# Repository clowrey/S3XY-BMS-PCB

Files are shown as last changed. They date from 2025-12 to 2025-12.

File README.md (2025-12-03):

# isoSPI-M3Y-BMS-PCB

**Hardware Design for Tesla Model 3/Y Battery Management System**





This repository contains the **KiCad PCB design files** for a replacement Battery Management System (BMS) designed for Tesla Model 3 and Model Y battery packs. This hardware interfaces with high-voltage (400V) battery modules using the isoSPI protocol and provides comprehensive monitoring, control, and safety features.

🔗 **Companion Firmware Repository:** [isoSPI-M3Y-BMS](https://github.com/clowrey/isoSPI-M3Y-BMS)

---

## ⚡ Overview

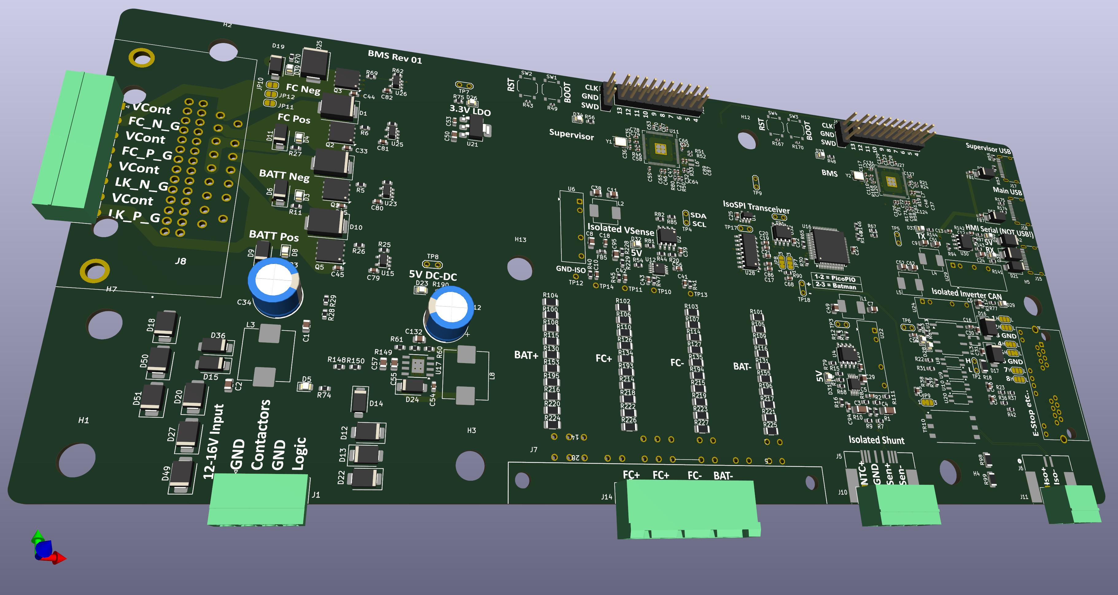
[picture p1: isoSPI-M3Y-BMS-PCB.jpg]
PCB Design


This PCB design implements a complete BMS controller capable of:

- **Direct BMB Communication**: isoSPI master interface for Battery Management Boards
- **High Precision Monitoring**: Current, voltage, temperature, and power measurement
- **CAN Bus Integration**: 500kbps communication with vehicle systems and inverters
- **Contactor Control**: Safe sequenced activation of high-voltage contactors
- **Cell Balancing**: Individual cell balancing control through BMB modules
- **Safety Features**: Overcurrent, overvoltage, undervoltage, and thermal protection

### 🔋 Tesla Model 3/Y Battery Pack Architecture

Tesla Model 3 and Model Y battery packs utilize a modular architecture:

- **Cell Configuration:** 4416 cells (96s46p) in 4 modules
- **Module Configuration:** 24 cells in series per module (96 total series groups)
- **Nominal Voltage:** ~350V (fully charged: ~400V, discharged: ~280V)
- **Capacity:** Varies by pack (50-82 kWh depending on model/year)
- **Battery Management Boards (BMBs):** Each module contains BMBs that monitor cell groups
- **Communication:** Original packs use proprietary Tesla BMS; this project replaces it

**Why Replace the BMS?**
- Reuse Tesla packs in DIY electric vehicle conversions
- Second-life energy storage systems
- Research and educational purposes
- Open-source alternative to proprietary systems

### 🔌 Key Hardware Features

| Feature | Implementation |
|---|---|
| **Microcontroller** | Raspberry Pi RP2354B (dual Cortex-M33, 150MHz) |
| **Current Sensing** | Texas Instruments INA228 (20-bit ADC) |
| **Pack Voltage** | 4-channel ADC with precision voltage dividers |
| **CAN Interface** | Hardware CAN transceiver (500kbps) |
| **isoSPI** | Differential Manchester encoding, galvanic isolation |
| **Contactor Drivers** | 4-channel PWM with inrush control |
| **Operating Voltage** | 12V nominal input |
| **High Voltage Rating** | Up to 400V DC battery pack |

---

## 📁 Repository Structure

```
isoSPI-M3Y-BMS-PCB/
├── isoSPI-M3Y-BMS-PCB.kicad_pro    # KiCad project file
├── isoSPI-M3Y-BMS-PCB.kicad_sch    # Main schematic design
├── isoSPI-M3Y-BMS-PCB.kicad_pcb    # PCB layout
├── BMS_Library/                     # Custom component library
│   ├── BMS_Library.kicad_sym        # Symbol library
│   └── BMS_Library.pretty/          # Footprint library
├── RP2350_KiCad/                    # RP2350 MCU resources
│   ├── RP2350A_QFN-60*.kicad_mod    # Footprints
│   ├── RP2350A-QFN60.step           # 3D model
│   └── rp2350a-qfn60.kicad_sym      # Symbol
├── bms.3dshapes/                    # 3D models for connectors
├── reassociate_components.py        # Component re-linking utility
├── apply_mapping.py                 # Reference mapping tool
└── fabrication-toolkit-options.json # Manufacturing outputs config
```

---

## 🚀 Getting Started

### Prerequisites

- **KiCad 8.0+** - [Download here](https://www.kicad.org/download/)
- **Python 3.7+** (for utility scripts)
- Basic understanding of PCB design and high-voltage safety

### Opening the Project

1. **Clone the repository:**
   ```bash
   git clone https://github.com/clowrey/isoSPI-M3Y-BMS-PCB.git
   cd isoSPI-M3Y-BMS-PCB
   ```

2. **Open in KiCad:**
   - Launch KiCad
   - Open `isoSPI-M3Y-BMS-PCB.kicad_pro`

3. **Library Configuration:**
   - Libraries are configured in local `sym-lib-table` and `fp-lib-table`
   - Project-specific libraries (`BMS_Library`, `RP2350_KiCad`) should load automatically
   - If missing components appear, verify library paths in KiCad preferences

### Viewing the Design

- **Schematic:** Open `isoSPI-M3Y-BMS-PCB.kicad_sch` to view circuit design
- **PCB Layout:** Open `isoSPI-M3Y-BMS-PCB.kicad_pcb` to view board layout
- **3D View:** Press `Alt+3` in PCB editor to visualize the assembled board

---

## 🛠️ Design Sections

### Power Supply
- 12V input with protection and filtering
- 3.3V LDO for MCU and logic
- Isolated power for isoSPI interface

### Microcontroller (RP2354B)
- QFN-60 package with thermal pad
- Crystal oscillator for precision timing
- JTAG/SWD debug interface
- Boot mode selection

### Current Sensing (INA228)
- Shunt resistor-based measurement
- 20-bit delta-sigma ADC
- Bidirectional current monitoring
- I2C interface to MCU

### Voltage Monitoring
- 4-channel pack voltage measurement
- Precision resistor dividers (high voltage to ADC range)
- Individual cell voltages via isoSPI
- 12-bit internal ADC

### isoSPI Interface
- Differential transformer coupling
- Manchester encoding via PIO
- Galvanic isolation from high voltage
- Master and snooper mode support

### CAN Bus
- Hardware CAN transceiver
- 120Ω termination (configurable)
- PIO-based CAN 2.0B implementation
- 500kbps operation

### Contactor Control
- 4 independent high-current outputs
- PWM inrush current limiting
- Sequenced activation logic
- Flyback protection diodes

### Connectors
- High-voltage battery pack connector
- 12V power input
- CAN bus connector
- USB programming interface
- Debug headers

---

## 🔧 Utility Scripts

### `reassociate_components.py`

Re-links PCB footprints to schematic symbols after copying design sections. This is essential when:
- Copying and pasting PCB sections (breaks UUID links)
- Duplicating circuits for multi-channel designs
- Recovering from schematic/PCB desynchronization

**Usage:**
```bash
python reassociate_components.py
```

The script:
1. Parses both `.kicad_sch` and `.kicad_pcb` files
2. Matches components by reference designator and type
3. Updates PCB footprints with correct schematic UUIDs
4. Creates backup before modification

### `apply_mapping.py`

Applies specific component reference remapping (e.g., when renaming U11→U27). Updates both reference designators and UUID linkages.

**Usage:**
```bash
python apply_mapping.py
```

---

## 📦 Manufacturing

### Generating Production Files

The project includes `fabrication-toolkit-options.json` for automated manufacturing output generation.

**Recommended manufacturers:**
- JLCPCB
- PCBWay
- OSH Park
- Any PCB fab supporting 4+ layer boards

### PCB Specifications

| Parameter | Value |
|---|---|
| **Layers** | 4 (or as designed) |
| **PCB Thickness** | 1.6mm standard |
| **Copper Weight** | 2oz for power traces |
| **Min Trace/Space** | 6/6 mil (typical) |
| **Solder Mask** | Green (or preference) |
| **Silkscreen** | White |
| **Surface Finish** | ENIG or HASL |

### High-Voltage Considerations

⚠️ **CRITICAL SAFETY REQUIREMENTS:**

- **Clearances:** Maintain minimum 4mm creepage distance for 400V
- **Isolation:** isoSPI and current sensing must maintain galvanic isolation
- **Testing:** All HV sections require hi-pot testing before energization
- **Conformal Coating:** Recommended for high-voltage traces
- **Certifications:** May require UL/CE certification for commercial use

---

## 🔌 Assembly Notes

### Component Sourcing

- Most components available from Digi-Key, Mouser, or LCSC
- RP2354B: Available from Raspberry Pi approved distributors
- INA228: Texas Instruments or authorized distributors
- Connectors: Match to Tesla pack interface specifications

### Assembly Sequence

1. **SMD Components:** Reflow solder all surface mount parts
2. **Through-hole:** Hand solder connectors and large components
3. **Inspection:** Verify all solder joints and orientation
4. **Testing:** Low-voltage functional testing before HV connection
5. **Programming:** Flash firmware via USB or SWD
6. **Calibration:** ADC and current sensing calibration routines

---

## 🔗 Firmware Integration

This PCB is designed to work with the companion firmware:

📦 **[isoSPI-M3Y-BMS Firmware](https://github.com/clowrey/isoSPI-M3Y-BMS)**

### ✅ Implemented Features (v2.0.0)

**Hardware Drivers:**
- RP2354B microcontroller with dual Cortex-M33 cores
- INA228 current/voltage/power sensor driver
- Internal ADC for pack voltage monitoring (4 channels)
- Contactor control (4 channels, sequenced activation)
- Serial command processing (30+ commands)
- CAN bus interface (can2040, 500kbps broadcast)
- isoSPI PIO master implementation
- isoSPI passive bus snooper
- Unified BMB test interface
- Runtime interface switching (Batman/isoSPI)

**System Features:**
- Parameter system with 108+ BMS parameters
- Coulomb counting for SOC tracking
- Automatic 10Hz pack status CAN broadcasting
- Statistics tracking for TX/RX/errors
- Configurable message IDs and data formatting

### 🚧 In Progress (Phase 3)

- BATMan/isoSPI interface switching
- Runtime interface control (automatic disable/enable)
- Full BMS state machine
- Cell voltage reading via isoSPI
- Cell balancing control
- Temperature monitoring

### 📋 Pending (Phases 4-6)

- Hardware testing and validation
- Calibration routines for ADC
- Flash storage for calibration data
- Error handling and recovery
- Extended testing (24+ hours)
- Performance optimization
- Documentation completion

### Getting Started with Firmware

1. Clone the firmware repository
2. Install Pico SDK and build tools (CMake-based)
3. Build the project:
   ```bash
   cd isoSPI-M3Y-BMS
   mkdir build && cd build
   cmake ..
   make
   ```
4. Flash to RP2354B via USB or SWD
5. Connect via serial interface (115200 baud)
6. Configure using serial commands
7. Optional: Integrate with ESPHome for monitoring and display

### Optional: ESPHome Display Integration

The firmware supports integration with ESPHome for advanced monitoring via touchscreen displays:

**ESPHome Features:**
- **Three-Page Display Interface:**
  - Main overview with key parameters
  - Detailed battery information
  - Cell voltage graph (all 108 cells visualized)
- **Real-time Monitoring:** Live parameter updates every 5-10 seconds
- **Touch Controls:** Balance on/off, page navigation
- **Home Assistant Integration:** All BMS parameters as HA entities
- **Professional UI:** LVGL-based interface optimized for 480x320 displays

**Supported Hardware:**
- JC4832W535 480x320 QSPI touchscreen
- ESP32-S3 based display modules
- WiFi connectivity for OTA updates

See the [ESPHome interface documentation](https://github.com/clowrey/isoSPI-M3Y-BMS/tree/main/esphome-interface) in the firmware repository for setup instructions.

---

## ⚠️ Hardware Safety

### ⚡ HIGH VOLTAGE WARNING ⚡

**This system interfaces with 400V battery packs that can deliver LETHAL current.**

- **Only qualified personnel should work on high-voltage systems**
- **Proper isolation and safety measures required**
- **Use appropriate personal protection equipment (PPE)**
- **Follow all electrical safety protocols**
- **Discharge pack completely before service**
- **EV battery systems can deliver lethal current**
- **Follow all lockout/tagout procedures**

### ⚠️ DEVELOPMENT STATUS

- **This is a development version (v2.0.0)**
- **isoSPI implementation is experimental**
- **BATMan protocol partially implemented**
- **Extensive testing required before production use**
- **USE AT YOUR OWN RISK**
- No warranty expressed or implied
- Not certified for commercial EV use
- User assumes all responsibility for safety

### Recommended Safety Equipment

- Insulated high-voltage gloves (Class 00 minimum)
- Safety glasses with side shields
- Insulated tools rated for 1000V
- Multimeter rated for CAT III 600V or higher
- Isolation transformer for bench testing
- Emergency shutdown procedures
- First aid and emergency response plan

---

## 📚 Documentation

### Related Resources

- **Firmware Repository:** [isoSPI-M3Y-BMS](https://github.com/clowrey/isoSPI-M3Y-BMS)
- **RP2354B Datasheet:** [Raspberry Pi Documentation](https://datasheets.raspberrypi.com/rp2350/rp2350-datasheet.pdf)
- **INA228 Datasheet:** [Texas Instruments](https://www.ti.com/product/INA228)
- **Pico SDK:** [Raspberry Pi Pico SDK](https://github.com/raspberrypi/pico-sdk)
- **can2040 Library:** [Kevin O'Connor's can2040](https://github.com/KevinOConnor/can2040)
- **Original BATMan BMS:** Damien Maguire & Tom de Bree

### Additional Documentation

- Schematic PDF exports (generate from KiCad)
- Bill of Materials (generate from KiCad BOM tool)
- Assembly drawings (generate from KiCad fabrication outputs)
- Test procedures (in firmware repository)
- CAN message format documentation (in firmware repo)
- Calibration procedures (in firmware repo)

---

## 🤝 Contributing

Contributions are welcome! Please:

1. Fork the repository
2. Create a feature branch (`git checkout -b feature/improvement`)
3. Make your changes with clear commit messages
4. Test thoroughly (especially high-voltage sections)
5. Submit a pull request with detailed description

**Areas for contribution:**
- Schematic improvements
- PCB layout optimization
- Additional protection circuits
- Manufacturing DFM improvements
- Documentation enhancements
- Test jig designs

---

## 📝 License

This project is licensed under the **GNU General Public License v3.0** - see the [LICENSE](LICENSE) file for details.

This program is free software: you can redistribute it and/or modify it under the terms of the GNU General Public License as published by the Free Software Foundation, either version 3 of the License, or (at your option) any later version.

This program is distributed in the hope that it will be useful, but WITHOUT ANY WARRANTY; without even the implied warranty of MERCHANTABILITY or FITNESS FOR A PARTICULAR PURPOSE. See the GNU General Public License for more details.

**In summary:**
- ✅ Free to use, modify, and distribute
- ✅ Must disclose source code
- ✅ Must use same GPL-3.0 license
- ✅ State changes made to original
- ❌ No warranty provided

---

## 🙏 Acknowledgments

- **Damien Maguire & Tom de Bree** - Original BATMan BMS software
- **ESPHome Community** - Framework and component support
- **Kevin O'Connor** - can2040 library for RP2040/RP2350
- **Raspberry Pi Foundation** - Pico SDK and excellent documentation
- **Texas Instruments** - INA228 current sensing IC
- **KiCad Community** - Excellent open-source EDA tools
- **Analog Devices** - isoSPI protocol and reference designs
- **Tesla Motors** - Battery module architecture reference

---

## 📧 Support & Contact

- **Issues:** Use GitHub Issues for bug reports and feature requests
- **Discussions:** GitHub Discussions for general questions
- **Pull Requests:** Contributions welcome via GitHub PR

---

## 📋 Changelog

### Hardware Version 2.0 (December 2025) - RP2354B Platform

**Complete platform migration supporting firmware v2.0.0:**

#### **Major Hardware Changes**

* **Microcontroller:** Migrated from ESP32 to Raspberry Pi RP2354B
  - Dual Cortex-M33 cores @ 150MHz
  - QFN-60 package with thermal management
  - Native USB support for programming and debugging
  - Hardware SWD debug interface

* **Current Sensing:** Replaced AS8510 with Texas Instruments INA228
  - 20-bit delta-sigma ADC
  - High-side and low-side sensing capability
  - I2C interface with configurable address
  - Integrated power calculation

* **Pack Voltage Monitoring:** Added 4-channel internal ADC monitoring
  - Precision voltage dividers for 400V → 3.3V range
  - 12-bit resolution
  - Individual channel filtering

* **CAN Bus:** Integrated hardware CAN transceiver
  - Native CAN 2.0B support via PIO
  - 500kbps operation
  - Configurable termination (120Ω)

#### **New Features**

* **isoSPI Implementation:**
  - Differential transformer coupling with galvanic isolation
  - PIO-based Manchester encoding/decoding
  - Master mode for direct BMB communication
  - Passive snooper mode for bus monitoring
  - Runtime switching between BATMan SPI and isoSPI

* **Enhanced Contactor Control:**
  - 4-channel PWM drivers with inrush limiting
  - Sequenced activation logic in hardware
  - Flyback protection for inductive loads

* **Unified Testing Interface:**
  - Single test connector for both BATMan and isoSPI modes
  - Automatic interface detection

#### **Firmware Compatibility**

This hardware revision requires **firmware v2.0.0 or later** from the companion repository:
- [isoSPI-M3Y-BMS v2.0.0 Changelog](https://github.com/clowrey/isoSPI-M3Y-BMS#changelog)

### Hardware Version 1.x (2024-2025) - ESP32 Platform

**Original ESP32-based design:**
- ESP32-WROOM-32 microcontroller
- AS8510 current sensor
- Arduino framework
- BATMan SPI communication only
- ESPHome integration support

---

## ⚙️ Project Status

**Current Hardware Version:** v2.0 (RP2354B-based design)

**PCB Development Status:**
- ✅ Schematic design complete
- ✅ Component selection finalized
- 🔄 PCB layout in progress
- ⏳ Design rule check (DRC) pending
- ⏳ Prototype fabrication pending
- ⏳ Hardware validation pending
- ⏳ Production testing pending

**Companion Firmware Status:** 
- **Version:** v2.0.0 (November 2025)
- **Status:** Active development
- **Phase:** isoSPI implementation in progress (Phase 3)
- **See:** [Firmware Repository](https://github.com/clowrey/isoSPI-M3Y-BMS) for detailed status

---

## 🔮 Future Enhancements

- [ ] Enhanced thermal management
- [ ] Additional redundant safety circuits
- [ ] Wireless monitoring interface
- [ ] Integrated display option
- [ ] Automotive-grade component variants
- [ ] Extended temperature range support
- [ ] Multi-pack support with CAN bridging
- [ ] Production test fixture design

---

**⚡ Building the future of open-source battery management systems ⚡**

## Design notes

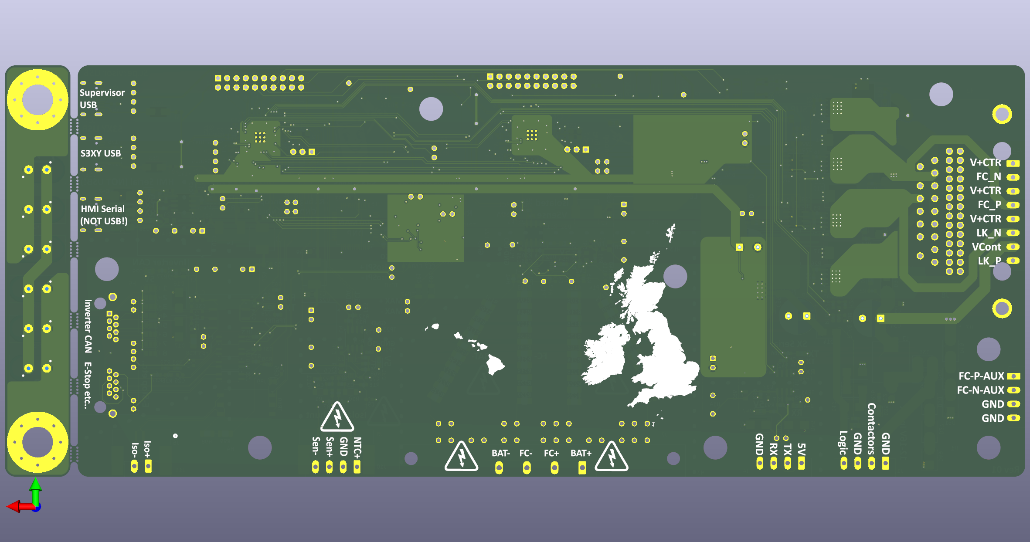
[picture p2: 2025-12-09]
S3XY-BMS-REV0-Back.png

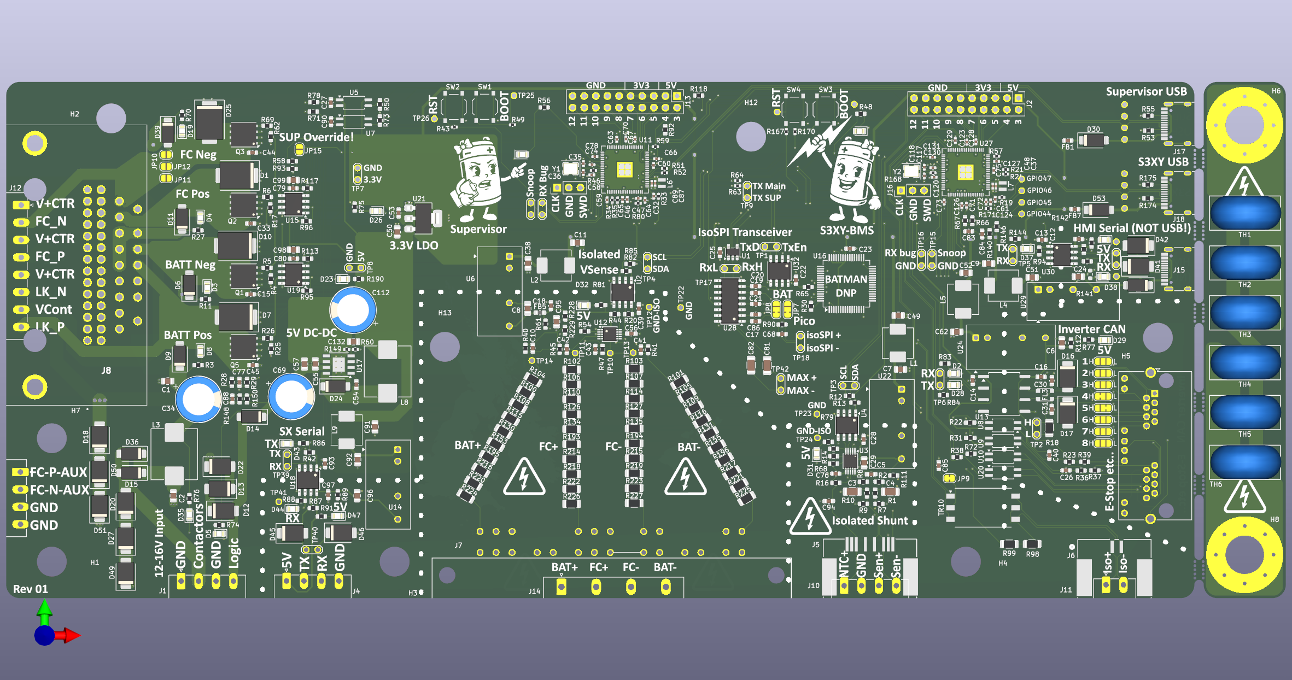
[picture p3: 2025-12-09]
S3XY-BMS-REV0.png

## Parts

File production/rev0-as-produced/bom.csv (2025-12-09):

Designator | Footprint | Quantity | Value | LCSC Part #
C1, C2, C24, C29, C55, C57, C6, C8, C96, C98, C99 | 0805 | 11 | 10uF | C440198
C10, C12, C13, C14, C15, C16, C21, C22, C23, C25, C28, C33, C39, C41, C42, C43, C44, C45, C5, C54, C56, C76, C77, C79, C80, C83, C84, C85, C88, C93, C94, C97 | 0603 | 32 | 100nf | C14663
C11, C132, C38, C49, C50, C51, C52, C62, C7, C9, C91, C92, C95 | 0805 | 13 | 22uF | C45783
C112, C34, C69 | CP_Radial_D10.0mm_P5.00mm | 3 | 680uF | C46550429
C117, C118, C35, C36 | 0402 | 4 | 15pF | C1548
C120, C123, C124, C126, C127, C128, C129, C130, C131, C46, C58, C59, C60, C63, C64, C65, C66, C67, C70, C71, C73, C74, C75, C78 | 0402 | 24 | 100n | C1525
C17, C18, C19, C20, C26, C27, C40, C86, C90 | 0603 | 9 | 1uF | C15849
C3, C4 | 1206 | 2 | 4.7uF 50V | C29823
C30, C31, C68 | 0603 | 3 | 100pF | C14858
C32, C37, C47, C48, C61, C72, C87, C89 | 0402 | 8 | 4.7u | C23733
C53 | 0603 | 1 | 4.7uF | C19666
C81, C82 | 1206 | 2 | 1nF | C9196
D1, D10, D25, D7 | D_SMC | 4 | SMCJ33CA | C224050
D11, D14, D15, D21, D24, D30, D36, D39, D53, D6, D9 | D_SMA | 11 | SS54 | C22452
D12, D13, D16, D17, D18, D20, D22, D27, D41, D42, D45, D46, D49, D50, D51 | D_SMB | 15 | SMB6.8CA | C78395
D19, D2, D3, D38, D4, D44, D8 | 0805 | 7 | Green | C2297
D23, D26, D29, D31, D32, D35, D40, D47, D5 | 0805 | 9 | White | C34499
D28, D33, D34, D37, D43 | 0805 | 5 | Red | C84256
FB1, FB7 | 0603 | 2 | 120Ω@100MHz | C14709
FB5 | 0603 | 1 | 600R@100MHz | C1002
FL3 | FILTER-SMD_4P-L3.2-W2.5-BL | 1 | SDCW3225S-2-102TF | C192586
GPIO44, GPIO45, GPIO46, GPIO47, TP10, TP11, TP12, TP13, TP14, TP22, TP23, TP24, TP25, TP26, TP27, TP28, TP29, TP30, TP31, TP32, TP33, TP34, TP35, TP36, TP37, TP38, TP41 | TestPoint_THTPad_D1.5mm_Drill1.0mm | 27 | TP
J15, J17, J18 | USB_C_Receptacle_HRO_TYPE-C-31-M-12 | 3 | USB_C_Receptacle_USB2.0_16P | C2765186
J3 | RJ45_Amphenol_RJHSE538X-02 | 1 | 8P8C_LED_Shielded_x2 | C3010546
J6 | CONN_SD-34912-001_02_MOL | 1 | OEM Connector | C587318
JP10, JP11, JP12 | SolderJumper-2_P1.3mm_Open_RoundedPad1.0x1.5mm | 3 | Jumper_2_Open
L1, L2, L4, L5, L9 | L_Changjiang_FXL0630 | 5 | 6.8uh | C167221
L3, L8 | L_Changjiang_FXL1040 | 2 | 22uh 5.5A | C475917
L6, L7 | L_pol_2016 | 2 | 3.3uh | C42411119
Q1, Q2, Q3, Q5 | AO_DFN-8-1EP_5.55x5.2mm_P1.27mm_EP4.12x4.6mm | 4 | CRSM034N06L2 | C467174
R1, R10 | 0603 | 2 | 150r | C22808
R100, R101, R102, R103, R104, R105, R106, R107, R108, R109, R110, R114, R115, R116, R126, R127, R130, R131, R134, R135, R153, R155, R193, R194, R195, R196, R214, R215, R216, R217, R218, R219, R220, R221, R222, R223, R224, R225, R226, R227, R98, R99 | 1206 | 42 | 1M | C17927
R11, R146, R27, R3, R40, R41, R45, R47, R70, R74, R76 | 0603 | 11 | 24k | C23352
R111, R112, R61, R7, R89, R9 | 0603 | 6 | 510r | C23193
R113, R117, R12, R13, R14, R15, R174, R175, R20, R44, R53, R55, R82, R85, R93, R95, R96 | 0603 | 17 | 5.1k | C23186
R118, R23, R36, R38, R42, R58, R71, R72, R78, R87, R92, R94, R97 | 0603 | 13 | 1k | C21190
R140, R142, R143, R144, R148, R16, R190, R22, R29, R31, R48, R50, R54, R56, R66, R67, R68, R73, R75, R77, R79, R81, R83, R84, R86, R88, R91 | 0603 | 27 | 10k | C25804
R149, R167, R168, R170, R34, R35, R43, R46, R49, R57, R59, R63, R64 | 0402 | 13 | 1k | C11702
R150, R17, R25, R28, R4, R62 | 0603 | 6 | 100k | C25803
R171, R19, R33, R80 | 0402 | 4 | 33r | C25105
R18 | 1206 | 1 | 120r | C17909
R2, R37, R39, R8 | 0603 | 4 | 2.2k | C4190
R21, R24, R51, R52 | 0402 | 4 | 22R | C25092
R228, R229 | 0603 | 2 | 220r | C22962
R26, R5, R6, R69 | 0603 | 4 | 33R | C23140
R30, R90 | 0603 | 2 | 100r | C22775
R60 | 0402 | 1 | 3.3k | C25890
R65 | 0603 | 1 | 2.7k | C13167
SW1, SW2, SW3, SW4 | SW_Push_1P1T_XKB_TS-1187A | 4 | TS-1187A-B-A-B | C318884
TH1, TH2, TH3, TH4, TH5, TH6 | RV_Disc_D15.5mm_W7.5mm_P5.0mm | 6 | B59451C1130B070 | C2762811
TP1, TP15, TP16, TP17, TP18, TP19, TP2, TP20, TP21, TP3, TP39, TP4, TP40, TP42, TP5, TP6, TP7, TP8, TP9 | TestPoint_2Pads_Pitch2.54mm_Pad1.5_Drill1.0mm | 19 | TestPoint_2Pole
TR10 | HM2113ZNLT | 1 | HM2113ZNLT | C5730533
U1 | SOT-23-5 | 1 | SN74LV1T08DBVR | C2682144
U10, U20, U5, U7, U8, U9 | SSOP-4_4.4x2.6mm_P1.27mm | 6 | LTV-217-B-G | C115450
U11, U27 | RP2350-QFN-80-1EP_10x10_P0.4mm_EP3.4x3.4mm_ThermalVias | 2 | RP2354B | C39843328
U12 | TSSOP-10_3x3mm_P0.5mm | 1 | ADS1115 | C37593
U13 | SOP-8_6.62x9.15mm_P2.54mm | 1 | ISO1050DUB | C16428
U14, U22, U24, U6 | H0505S-1WR2 | 4 | F0505S-1WR3 | C7465182
U15, U19 | SOIC-8_3.9x4.9mm_P1.27mm | 2 | UCC27524DR | C465729
U17 | TI_SO-PowerPAD-8_ThermalVias | 1 | TPS5430DDAR | C9864
U18, U2, U30, U4 | SOIC-8_3.9x4.9mm_P1.27mm | 4 | ISO1540 | C179739
U21 | SOT-223-3_TabPin2 | 1 | AMS1117-3.3 | C6186
U28 | SOIC-16_3.9x9.9mm_P1.27mm | 1 | AM26LV32EIDR | C527448
U29 | Converter_DCDC_TRACO_TRA3-xxxx_THT | 1 | B0505S-3WR2 | C7500927
U3 | VSSOP-10_3x3mm_P0.5mm | 1 | INA228 | C5214669
U32 | SOIC-8_3.9x4.9mm_P1.27mm | 1 | SP3485EN-L/TR | C8963
Y1, Y2 | Crystal_SMD_3225-4Pin_3.2x2.5mm | 2 | ABM8-272-T3 | C20625731

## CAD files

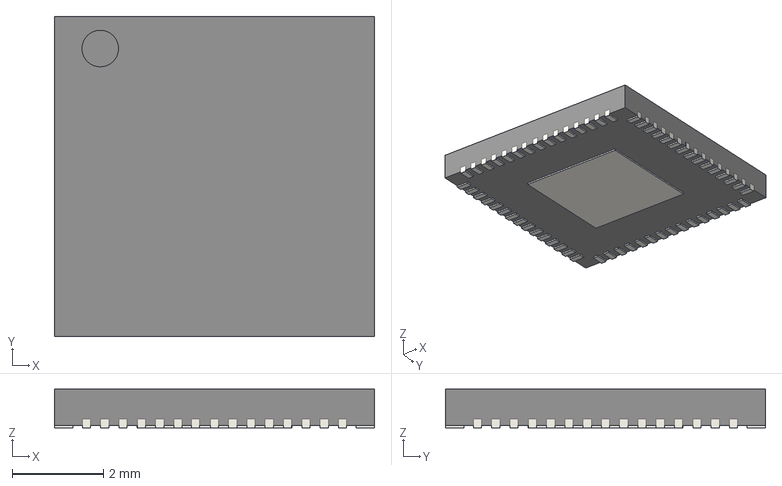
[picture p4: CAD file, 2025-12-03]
RP2350_KiCad/RP2350A-QFN60.step
7.00 x 7.00 x 0.85 mm

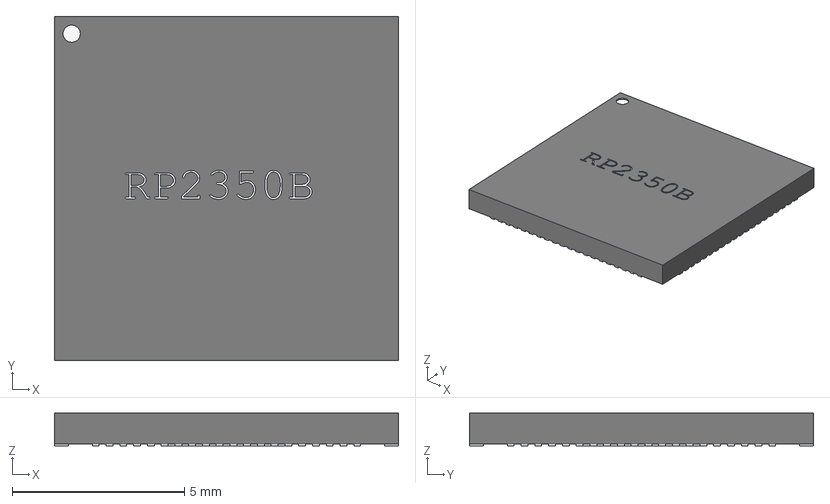
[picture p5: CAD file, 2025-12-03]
RP2350B/RP2350_QFN80.step
10.0 x 10.0 x 0.95 mm

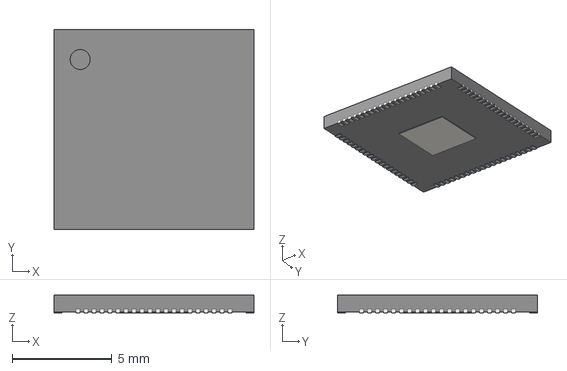
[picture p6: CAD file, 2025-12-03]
RP2350_KiCad/RP2350B-QFN80.step
10.0 x 10.0 x 0.9 mm

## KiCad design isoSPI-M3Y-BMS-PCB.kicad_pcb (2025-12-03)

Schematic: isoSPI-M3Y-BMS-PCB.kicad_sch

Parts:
BT1, BT3, BT4, BT5, BT6, BT7, BT8, BT9: ~100V Brick
C1, C2, C55, C57: 10uF; C_0805_2012Metric; Voltage 50V; JLCPCB Part # C440198
C3, C4: 4.7uF 50V; C_1206_3216Metric; JLCPCB Part # C29823
C5, C94: 100nf; C_0603_1608Metric_Pad1.08x0.95mm_HandSolder; JLCPCB Part # C14663
C6, C24, C29: 10uF; C_0805_2012Metric; Voltage 50V X5R; JLCPCB Part # C440198
C7, C9, C49, C50, C51, C52, C62, C95, C132: 22uF; C_0805_2012Metric; Voltage 25V X5R; JLCPCB Part # C45783
C8: 10uF; C_0805_2012Metric_Pad1.18x1.45mm_HandSolder; Voltage 50V; JLCPCB Part # C440198
C10, C41, C42, C43: 100nf; C_0603_1608Metric; JLCPCB Part # C14663
C11, C38: 22uF; C_0805_2012Metric_Pad1.18x1.45mm_HandSolder; Voltage 25V; JLCPCB Part # C45783
C12, C13, C14, C15, C16, C21, C22, C23, C25, C28, C33, C44, C45, C54, C79, C80, C81, C82, C85: 100nF; C_0603_1608Metric; JLCPCB Part # C14663
C17, C19, C20, C86: 1uF; C_0603_1608Metric; JLCPCB Part # v
C18: 1uF; C_0603_1608Metric; JLCPCB Part # C15849
C26, C40: 1uF; C_0603_1608Metric_Pad1.08x0.95mm_HandSolder; JLCPCB Part # C15849
C27, C32, C47, C61, C69, C72: 4.7u; C_0402_1005Metric; JLCPCB Part # C23733
C30, C31, C68: 100pF; C_0603_1608Metric; JLCPCB Part # C14858
C34, C112: 680uF; CP_Radial_D10.0mm_P5.00mm; Voltage 35V Polymer
C35, C36, C117, C118: 15pF; C_0402_1005Metric; JLCPCB Part # C1548
C37, C48, C87, C89: 4.7u; C_0402_1005Metric_small_pads; JLCPCB Part # C23733
C39, C56: 100nF; C_0603_1608Metric_Pad1.08x0.95mm_HandSolder; JLCPCB Part # C14663
C46, C58, C59, C60, C63, C64, C65, C66, C67, C70, C71, C73, C74, C75, C78, C120, C123, C124, C126, C127, C128, C129, C130, C131: 100n; C_0402_1005Metric; JLCPCB Part # C1525
C53: 4.7uF; C_0603_1608Metric; JLCPCB Part # C19666
D1, D7, D10, D25: SM15T36CA; D_SMC; JLCPCB Part # C1976312
D2, D3, D4, D8, D19, D38: Green; LED_0805_2012Metric; JLCPCB Part # C2297
D5, D23, D26, D29, D31, D32, D40: White; LED_0805_2012Metric; JLCPCB Part # C34499
D6, D9, D11, D14, D15, D21, D24, D30, D36, D39, D53: SS54; D_SMA; JLCPCB Part # C22452
D12, D13, D16, D17, D18, D20, D22, D27, D41, D42, D49, D50, D51: SMB6.8CA; D_SMB; JLCPCB Part # C78395
D28, D33, D34, D37: Red; LED_0805_2012Metric; JLCPCB Part # C84256
F1, F8: Pyro Fuse
F9, F11: 63A HV DC
FB1, FB7: 120Ω@100MHz; C_0603_1608Metric; JLCPCB Part # C14709
FB5: 600R@100MHz; L_0603_1608Metric_Pad1.05x0.95mm_HandSolder; JLCPCB Part # C1002
FL3: SDCW3225S-2-102TF; FILTER-SMD_4P-L3.2-W2.5-BL; JLCPCB Part # C192586
H1, H2, H3, H4, H5, H7, H12, H13: MountingHole_Pad; MountingHole_6.5mm
J1, J10: Screw_Terminal_01x04; PhoenixContact_MC_1,5_4-G-3.81_1x04_P3.81mm_Horizontal
J2, J13: Conn_02x10_Odd_Even; PinHeader_2x10_P2.54mm_Vertical
J3: 8P8C_LED_Shielded_x2; RJ45_Amphenol_RJHSE538X-02; JLCPCB Part # C3010546
J5: OEM Shunt Connector; CONN_ZE05H-8DP-2H_HIR
J6: 349128020; CONN_SD-34912-001_02_MOL; JLCPCB Part # C587318
J7: OEM HV Sense Connector; CONN_173864-1_TYC
J8: OEM Connector; S44BRAD1AK
J9, J16: Conn_01x03; PinHeader_1x03_P2.54mm_Vertical
J11: Screw_Terminal_01x03; PhoenixContact_MC_1,5_2-G-3.81_1x02_P3.81mm_Horizontal
J12: Screw_Terminal_01x08; PhoenixContact_MC_1,5_8-G-3.81_1x08_P3.81mm_Horizontal
J14: Screw_Terminal_01x04; PhoenixContact_GMSTBA_2,5_4-G-7,62_1x04_P7.62mm_Horizontal
J15, J17, J18: USB_C_Receptacle_USB2.0_16P; USB_C_Receptacle_HRO_TYPE-C-31-M-12
JP1, JP2, JP7, JP8, JP9: SolderJumper_3_Bridged12; SolderJumper-3_P1.3mm_Bridged12_RoundedPad1.0x1.5mm_NumberL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
JP3, JP4, JP5, JP6, JP13, JP14: SolderJumper_3_Open; SolderJumper-3_P1.3mm_Open_RoundedPad1.0x1.5mm_NumberLabels
JP10, JP11, JP12: Jumper_2_Open; SolderJumper-2_P1.3mm_Open_RoundedPad1.0x1.5mm
K9, K14: Link Positive
K10, K16: FC Positive
K11, K17: FC Negative
K12, K15: Link Negative
K13, K18: Inverter
L1, L2, L4, L5: 6.8uh; L_Changjiang_FXL0630; JLCPCB Part # C167221
L3, L8: 22uh 5.5A; L_Changjiang_FXL1040; JLCPCB Part # C475917
L6, L7: 3.3u; L_pol_2016
Q1, Q2, Q3, Q5: CRSM034N06L2; AO_DFN-8-1EP_5.55x5.2mm_P1.27mm_EP4.12x4.6mm; JLCPCB Part # C467174
R1, R10: 150r; R_0603_1608Metric; JLCPCB Part # C22808
R2, R8: 2.2k; R_0603_1608Metric; JLCPCB Part # C4190
R3, R11, R27, R40, R41, R45, R47, R70, R74, R146: 24k; R_0603_1608Metric; JLCPCB Part # C23352
R4, R17, R25, R28, R62, R150: 100k; R_0603_1608Metric; JLCPCB Part # C25803
R5, R6, R26, R69, R90: 100R; R_0603_1608Metric; JLCPCB Part # C22775
R7, R9, R111, R112, R141: 510r; R_0603_1608Metric; JLCPCB Part # C23193
R12, R13, R14, R15, R20, R44, R53, R55, R82, R85, R174, R175: 5.1k; R_0603_1608Metric; JLCPCB Part # C23186
R16, R29, R48, R54, R56, R60, R66, R67, R68, R75, R77, R79, R83, R84, R140, R142, R143, R144, R148, R190: 10k; R_0603_1608Metric; JLCPCB Part # C25804
R18: 120r; R_1206_3216Metric; JLCPCB Part # C17909
R19, R33, R50, R58, R80, R171: 33r; R_0402_1005Metric; JLCPCB Part # C25105
R21, R24, R51, R52: 22R; R_0402_1005Metric; JLCPCB Part # C25092
R22, R31, R81: 10k; R_0603_1608Metric_Pad0.98x0.95mm_HandSolder; JLCPCB Part # C25804
R23, R36, R37, R38, R39, R42: 1.8k; R_0603_1608Metric; JLCPCB Part # C4177
R30: 100r; R_0603_1608Metric; JLCPCB Part # C22775
R32, R178: 25296nΩ
R34, R35, R43, R46, R49, R57, R59, R63, R64, R167, R168, R170: 1k; R_0402_1005Metric; JLCPCB Part # C11702
R61: 3k; R_0603_1608Metric; JLCPCB Part # C4211
R65: 2.7k; R_0603_1608Metric; JLCPCB Part # C13167
R94, R97: 1k; R_0603_1608Metric; JLCPCB Part # C21190
R98, R99, R100, R101, R102, R103, R104, R105, R106, R107, R108, R109, R110, R114, R115, R116, R126, R127, R130, R131, R134, R135, R153, R155, R193, R194, R195, R196, R214, R215, R216, R217, R218, R219, R220, R221, R222, R223, R224, R225, R226, R227: 1M; R_1206_3216Metric; JLCPCB Part # C17927
R149, R228, R229: 220r; R_0603_1608Metric; JLCPCB Part # C22962
R176: 27R 50W
SW1, SW2, SW3, SW4: TS-1187A-B-A-B; SW_Push_1P1T_XKB_TS-1187A; JLCPCB Part # C318884
TH1, TH2, TH3, TH4, TH5, TH6: B59451C1130B070; RV_Disc_D15.5mm_W7.5mm_P5.0mm; JLCPCB Part # C2762811
TP1, TP2, TP3, TP4, TP5, TP6, TP7, TP8, TP9, TP15, TP17, TP18: TestPoint_2Pole; TestPoint_2Pads_Pitch2.54mm_Drill0.9mm
TP10, TP11, TP12, TP13, TP14: TP; TestPoint_THTPad_D1.5mm_Drill1.0mm
TR10: HM2113ZNLT; JLCPCB Part # C5730533
U1, U15, U23, U25, U26: SN74LV1T08DBVR; SOT-23-5; JLCPCB Part # C2682144
U2, U4, U30: ISO1540; SOIC-8_3.9x4.9mm_P1.27mm; JLCPCB Part # C179739
U3: INA228; VSSOP-10_3x3mm_P0.5mm; JLCPCB Part # C5214669
U6, U22, U24: F0505S-1WR3; Converter_DCDC_TRACO_TEA1-xxxxHI_THT; JLCPCB Part # C7465182
U8, U9, U10, U20: LTV-217-B-G; SSOP-4_4.4x2.6mm_P1.27mm; JLCPCB Part # C115450
U11, U27: RP2354B; RP2350-QFN-80-1EP_10x10_P0.4mm_EP3.4x3.4mm_ThermalVias; JLCPCB Part # C39843328
U12: ADS1115; TSSOP-10_3x3mm_P0.5mm; LCSC Part # C37593
U13: ISO1050DUB; SOP-8_6.62x9.15mm_P2.54mm; LCSC Part # C16428
U16: BatMan; LQFP-64_10x10mm_P0.5mm; JLCPCB Part # DNP
U17: TPS5430DDAR; TI_SO-PowerPAD-8_ThermalVias; LCSC Part C9864
U21: AMS1117-3.3; SOT-223-3_TabPin2; JLCPCB Part # C6186
U28: AM26LV32EIDR; SOIC-16_3.9x9.9mm_P1.27mm; JLCPCB Part # C527448
U29: B0505S-3WR2; Converter_DCDC_TRACO_TRA3-xxxx_THT; LCSC Part # C7500927
U32: SP3485EN-L/TR; SOIC-8_3.9x4.9mm_P1.27mm; JLCPCB Part # C8963
Y1, Y2: ABM8-272-T3; Crystal_SMD_3225-4Pin_3.2x2.5mm; JLCPCB Part # C20625731

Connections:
3.3V Sense: R66.2, R67.1, U27.49 (GPIO40_ADC0)
5V Sense: R140.1, R146.2, U27.52 (GPIO41_ADC1)
+1V1: C48.1, C71.1, C120.1, C123.1, L7.1, U27.10 (DVDD), U27.32 (DVDD), U27.51 (DVDD), U27.65 (VREG_FB)
+1V1_2: C46.1, C58.1, C70.1, C87.1, L6.1, U11.10 (DVDD), U11.32 (DVDD), U11.51 (DVDD), U11.65 (VREG_FB)
+3.3V: C13.1, C14.1, C37.1, C53.2, C59.1, C60.1, C63.1, C64.1, C65.1, C66.1, C67.1, C73.1, C74.1, C75.1, C78.1, C89.1, C124.1, C126.1, C127.1, C128.1, C129.1, C130.1, C131.1, J2.1, J2.3, J2.5, J2.7, J2.9, J13.1, J13.3, J13.5, J13.7, J13.9, R12.1, R13.1, R19.2, R33.2, R50.2, R58.2, R59.1, R65.2, R66.1, R75.1, R82.1, R85.1, R94.1, TP7.2, U2.1 (VCC1), U4.1 (VCC1), U8.4, U9.4, U11.5 (IOVDD), U11.15 (IOVDD), U11.24 (IOVDD), U11.29 (IOVDD), U11.41 (IOVDD), U11.50 (IOVDD), U11.60 (IOVDD), U11.64 (VREG_VIN), U11.68 (USB_OTP_VDD), U11.69 (QSPI_IOVDD), U11.76 (IOVDD), U13.1 (VCC1), U21.2 (VO), U27.5 (IOVDD), U27.15 (IOVDD), U27.24 (IOVDD), U27.29 (IOVDD), U27.41 (IOVDD), U27.50 (IOVDD), U27.60 (IOVDD), U27.64 (VREG_VIN), U27.68 (USB_OTP_VDD), U27.69 (QSPI_IOVDD), U27.76 (IOVDD), U30.1 (VCC1)
+3V3: C21.1, C22.2, C25.1, U1.5 (VCC), U28.4 (G), U28.16 (VDD), U32.8 (VCC)
+5V: C9.2, C11.2, C23.1, C49.2, C50.2, C52.2, C79.2, C80.2, C81.2, C82.2, C112.1, C132.2, FB1.2, FB7.2, L1.2, L2.2, L4.2, L5.2, L8.1, R60.1, R146.1, R190.1, TP8.2, U15.5 (VCC), U16.5 (5V), U16.41 (5V), U16.47 (5V), U21.3 (VI), U23.5 (VCC), U25.5 (VCC), U26.5 (VCC)
/CAN 5V: C6.2, C16.2, R23.2, R37.2, R77.1, R112.1, U13.8 (VCC2), U24.7 (+Vout)
/CAN H: C30.2, D16.2 (A2), FL3.2, JP1.3 (B), JP2.1 (A), JP3.3 (B), JP4.3 (B), JP5.3 (B), JP6.3 (B), JP13.3 (B), JP14.3 (B), R18.2, TP2.2
/CAN L: C31.1, D17.1 (A1), FL3.3, JP1.1 (A), JP2.3 (B), JP3.1 (A), JP4.1 (A), JP5.1 (A), JP6.1 (A), JP13.1 (A), JP14.1 (A), R18.1, TP2.1
/Contactor_Input: D15.2 (A), D20.2 (A2), D36.2 (A), J1.2
/FC Pos: K10.13, K16.13, K18.1, R176.2, TH1.2, TH2.2, TH3.2
/FC-Neg-Jumper: C44.2, D19.1 (K), D25.2 (A2), D39.2 (A), JP10.1 (A), JP11.1 (A), JP12.1 (A), Q3.5 (D)
/GPIO0: R57.2, U27.77 (GPIO0)
/GPIO1: R63.2, U27.78 (GPIO1)
/GPIO2: R64.2, U27.79 (GPIO2)
/GPIO3: U27.80 (GPIO3)
/GPIO4: J2.2, U27.1 (GPIO4)
/GPIO5: J2.4, U27.2 (GPIO5)
/GPIO6: J2.6, U27.3 (GPIO6)
/GPIO7: J2.8, U27.4 (GPIO7)
/GPIO8: J2.10, U27.6 (GPIO8)
/GPIO9: J2.12, U27.7 (GPIO9)
/GPIO10: J2.14, U27.8 (GPIO10)
/GPIO11: J2.16, U27.9 (GPIO11)
/GPIO12: J2.18, U27.11 (GPIO12)
/GPIO13: J2.20, U27.12 (GPIO13)
/GPIO14: U27.13 (GPIO14)
/GPIO15: U27.14 (GPIO15)
/GPIO16: U27.16 (GPIO16)
/GPIO17: U27.17 (GPIO17)
/GPIO18: U27.18 (GPIO18)
/GPIO19: U27.19 (GPIO19)
/GPIO20: U27.20 (GPIO20)
/GPIO21: U27.21 (GPIO21)
/GPIO22: U27.22 (GPIO22)
/GPIO23: U27.23 (GPIO23)
/GPIO24: U27.25 (GPIO24)
/GPIO25: R48.1, U27.26 (GPIO25)
/GPIO44_ADC4: U27.55 (GPIO44_ADC4)
/GPIO45_ADC5: U27.56 (GPIO45_ADC5)
/GPIO46_ADC6: U27.57 (GPIO46_ADC6)
/GPIO47_ADC7: U27.58 (GPIO47_ADC7)
/Grn: J3.6, JP14.2 (C)
/HV Sense 5V: C18.2, C39.2, C56.2, FB5.2, R20.1, R44.1, R54.1, R81.2, R228.1, U2.8 (VCC2), U12.8 (VDD)
/Logic_Input: D12.2 (A2), D14.2 (A), J1.4
/MCU2_GPIO0: R59.2, U11.77 (GPIO0)
/MCU2_GPIO3: U11.80 (GPIO3)
/MCU2_GPIO4: J13.2, U11.1 (GPIO4)
/MCU2_GPIO5: J13.4, U11.2 (GPIO5)
/MCU2_GPIO6: J13.6, U11.3 (GPIO6)
/MCU2_GPIO7: J13.8, U11.4 (GPIO7)
/MCU2_GPIO8: J13.10, U11.6 (GPIO8)
/MCU2_GPIO9: J13.12, U11.7 (GPIO9)
/MCU2_GPIO10: J13.14, U11.8 (GPIO10)
/MCU2_GPIO11: J13.16, U11.9 (GPIO11)
/MCU2_GPIO12: J13.18, U11.11 (GPIO12)
/MCU2_GPIO13: J13.20, U11.12 (GPIO13)
/MCU2_GPIO15: U11.14 (GPIO15)
/MCU2_GPIO16: U11.16 (GPIO16)
/MCU2_GPIO17: U11.17 (GPIO17)
/MCU2_GPIO18: U11.18 (GPIO18)
/MCU2_GPIO19: U11.19 (GPIO19)
/MCU2_GPIO20: U11.20 (GPIO20)
/MCU2_GPIO21: U11.21 (GPIO21)
/MCU2_GPIO22: U11.22 (GPIO22)
/MCU2_GPIO23: U11.23 (GPIO23)
/MCU2_GPIO24: U11.25 (GPIO24)
/MCU2_GPIO25: R56.1, U11.26 (GPIO25)
/MCU2_GPIO26: U11.27 (GPIO26)
/MCU2_GPIO27: U11.28 (GPIO27)
/MCU2_GPIO28: U11.36 (GPIO28)
/MCU2_GPIO29: U11.37 (GPIO29)
/MCU2_GPIO30: U11.38 (GPIO30)
/MCU2_GPIO31: U11.39 (GPIO31)
/MCU2_GPIO32: U11.40 (GPIO32)
/MCU2_GPIO33: U11.42 (GPIO33)
/MCU2_GPIO34: U11.43 (GPIO34)
/MCU2_GPIO35: U11.44 (GPIO35)
/MCU2_GPIO36: U11.45 (GPIO36)
/MCU2_GPIO37: U11.46 (GPIO37)
/MCU2_GPIO38: R34.2, U11.47 (GPIO38)
/MCU2_GPIO39: R35.2, U11.48 (GPIO39)
/PH: C54.1, D24.1 (K), L8.2, U17.8 (PH)
/QSPI2_SCLK: U11.71 (QSPI_SCLK)
/QSPI2_SD0: U11.72 (QSPI_SD0)
/QSPI2_SD1: U11.74 (QSPI_SD1)
/QSPI2_SD2: U11.73 (QSPI_SD2)
/QSPI2_SD3: U11.70 (QSPI_SD3)
/QSPI2_SS: R49.1, U11.75 (QSPI_SS)
/QSPI_SCLK: U27.71 (QSPI_SCLK)
/QSPI_SD0: U27.72 (QSPI_SD0)
/QSPI_SD1: U27.74 (QSPI_SD1)
/QSPI_SD2: U27.73 (QSPI_SD2)
/QSPI_SD3: U27.70 (QSPI_SD3)
/QSPI_SS: R170.1, U27.75 (QSPI_SS)
/RUN: R167.2, SW4.2
/RUN_2: R43.1, U11.35 (RUN)
/SWCLK: J16.1, U27.33 (SWCLK)
/SWCLK_2: J9.1, U11.33 (SWCLK)
/SWD: J16.3, U27.34 (SWD)
/SWD_2: J9.3, U11.34 (SWD)
/Serial API 5V: C12.2, C24.2, D21.2 (A), R97.1, R141.1, R142.1, U29.6 (+Vout), U30.8 (VCC2)
/Serial API RX: D42.1 (A1), J15.A6 (D+), J15.B6 (D+), R143.1, U30.6 (SCL2)
/Serial API TX: D41.2 (A2), J15.A7 (D-), J15.B7 (D-), R97.2, U30.7 (SDA2)
/USB2_D+: J17.A6 (D+), J17.B6 (D+), R51.1
/USB2_D-: J17.A7 (D-), J17.B7 (D-), R52.1
/USB_D+: J18.A6 (D+), J18.B6 (D+), R21.1
/USB_D-: J18.A7 (D-), J18.B7 (D-), R24.1
/VREG2_AVDD: C32.1, R33.1, U11.61 (VREG_AVDD)
/VREG2_LX: L6.2, U11.63 (VREG_LX)
/VREG_AVDD: C61.1, R19.1, U27.61 (VREG_AVDD)
/VREG_LX: L7.2, U27.63 (VREG_LX)
/V_cont1: C2.2, D15.1 (K), D36.1 (K), L3.2
/Wht-Grn: J3.3, JP13.2 (C)
/XIN: C117.1, U27.30 (XIN), Y2.1
/XIN_2: C35.1, U11.30 (XIN), Y1.1
/XOUT: R168.1, U27.31 (XOUT)
/XOUT_2: R46.1, U11.31 (XOUT)
/iso+: C68.2, JP7.2 (C), R90.1, TP18.1, TR10.1 (TD-)
/iso-: C68.1, JP8.2 (C), R90.2, TP18.2, TR10.3 (TD+)
BatSPI_EN: U16.42 (EN), U27.46 (GPIO37)
BatSPI_SCK: U16.56 (SPI_SCK), U27.43 (GPIO34)
Batman IsoSPI+: JP8.3 (B), U16.62 (A-BMB)
Batman IsoSPI-: JP7.3 (B), U16.61 (A-BMB)
Batt Negative: J7.10, J14.4, R225.2
Batt Positive: J7.1, J14.1, R224.2
C FC-Neg (GND): J8.37, J12.2, JP10.2 (B), JP11.2 (B), JP12.2 (B)
C FC-Pos (GND): C33.2, D1.2 (A2), D4.1 (K), D11.2 (A), J8.36, J12.4, Q2.5 (D)
C Neg (GND): C15.2, D3.1 (K), D6.2 (A), D7.2 (A2), J8.42, J12.6, Q1.5 (D)
C Pos (GND): C45.2, D8.1 (K), D9.2 (A), D10.2 (A2), J8.41, J12.8, Q5.5 (D)
CAN Rx: R83.1, TP6.1, U13.2 (RXD)
CAN Tx: R84.1, TP6.2, U13.3 (TXD)
C_En: U11.13 (GPIO14), U15.2, U23.2, U25.2, U26.2
Drive Unit Pos: F9.1, K9.13, K10.14, K14.13, K16.14, TH4.1, TH5.1, TH6.1
Emergency Stop: R22.2, U8.3
Extra Input: R31.2, U9.3
Extra Output 1: R39.2
Extra Output 2: R38.2
FC Negative: J7.7, J14.3, R227.2
FC Positive: J7.4, J14.2, R226.2
FC-Neg: U26.1
FC-Pos: U25.1
GND: C1.1, C2.1, C7.1, C9.1, C11.1, C13.2, C14.2, C15.1, C21.2, C22.1, C23.2, C25.2, C27.2, C32.2, C33.1, C34.2, C35.2, C36.2, C37.2, C38.1, C44.1, C45.1, C46.2, C47.2, C48.2, C49.1, C50.1, C51.1, C52.1, C53.1, C55.1, C57.1, C58.2, C59.2, C60.2, C61.2, C62.1, C63.2, C64.2, C65.2, C66.2, C67.2, C69.2, C70.2, C71.2, C72.2, C73.2, C74.2, C75.2, C78.2, C79.1, C80.1, C81.1, C82.1, C85.1, C87.2, C89.2, C112.2, C117.2, C118.2, C120.2, C123.2, C124.2, C126.2, C127.2, C128.2, C129.2, C130.2, C131.2, C132.1, D1.1 (A1), D2.1 (K), D5.1 (K), D7.1 (A1), D10.1 (A1), D22.1 (A1), D23.1 (K), D24.2 (A), D25.1 (A1), D26.1 (K), D28.1 (K), D33.1 (K), D34.1 (K), D37.1 (K), D49.1 (A1), D51.1 (A1), J1.1, J1.3, J2.11, J2.13, J2.15, J2.17, J2.19, J9.2, J13.11, J13.13, J13.15, J13.17, J13.19, J16.2, J17.A1 (GND), J17.A12 (GND), J17.B1 (GND), J17.B12 (GND), J17.S1 (SHIELD), J18.A1 (GND), J18.A12 (GND), J18.B1 (GND), J18.B12 (GND), J18.S1 (SHIELD), Q1.1 (S), Q1.2 (S), Q1.3 (S), Q2.1 (S), Q2.2 (S), Q2.3 (S), Q3.1 (S), Q3.2 (S), Q3.3 (S), Q5.1 (S), Q5.2 (S), Q5.3 (S), R4.1, R17.1, R22.1, R25.1, R29.2, R31.1, R53.1, R55.1, R57.1, R62.1, R67.2, R99.1, R140.2, R148.2, R149.2, R174.1, R175.1, SW1.1, SW2.1, SW3.1, SW4.1, TP7.1, TP8.1, U1.3 (GND), U2.4 (GND1), U4.4 (GND1), U6.2 (-Vin), U10.2, U11.62 (VREG_PGND), U11.81 (GND), U13.4 (GND1), U15.3 (GND), U16.1 (GND), U16.3 (GND), U16.6 (GND), U16.7 (GND), U16.8 (GND), U16.9 (GND), U16.10 (GND), U16.11 (GND), U16.12 (GND), U16.13 (GND), U16.14 (GND), U16.15 (GND), U16.16 (GND), U16.17 (GND), U16.18 (GND), U16.19 (GND), U16.20 (GND), U16.21 (GND), U16.22 (GND), U16.23 (GND), U16.24 (GND), U16.25 (GND), U16.26 (GND), U16.27 (GND), U16.28 (GND), U16.29 (GND), U16.30 (GND), U16.31 (GND), U16.33 (GND), U16.34 (GND), U16.35 (GND), U16.36 (GND), U16.37 (GND), U16.38 (GND), U16.39 (GND), U16.40 (GND), U16.43 (GND), U16.45 (GND), U16.46 (GND), U16.49 (GND), U16.51 (GND), U16.60 (GND), U17.6 (GND), U17.9 (PowerPAD), U20.2, U21.1 (GND), U22.2 (-Vin), U23.3 (GND), U24.2 (-Vin), U25.3 (GND), U26.3 (GND), U27.62 (VREG_PGND), U27.81 (GND), U28.8 (GND), U28.12 (~G), U29.2 (-Vin), U30.4 (GND1), U32.2 (~RE), U32.5 (GND), Y1.2, Y1.4, Y2.2, Y2.4
GND CAN: C6.1, C16.1, C30.1, C31.2, D16.1 (A1), D17.2 (A2), D29.1 (K), J3.19, J3.SH, R112.2, U13.5 (GND2), U24.5 (-Vout)
GND_RS: C12.1, C24.1, D38.1 (K), D40.1 (K), D41.1 (A1), D42.2 (A2), J15.A1 (GND), J15.A12 (GND), J15.B1 (GND), J15.B12 (GND), J15.S1 (SHIELD), R141.2, U29.4 (-Vout), U30.5 (GND2)
GND_VSens: C8.1, C18.1, C39.1, C56.1, C95.1, D32.1 (K), R229.2, TP12.1, U2.5 (GND2), U6.5 (-Vout), U12.1 (ADDR), U12.3 (GND)
HMI Serial RX: R35.1, R94.2, TP5.2, U27.48 (GPIO39), U30.3 (SCL1)
HMI Serial TX: R34.1, R144.1, TP5.1, U27.47 (GPIO38), U30.2 (SDA1)
I2C SCL Shunt: R12.2, TP3.2, U4.3 (SCL1)
I2C SCL Vsense: R82.2, TP4.2, U2.3 (SCL1)
I2C SDA Shunt: R13.2, TP3.1, U4.2 (SDA1)
I2C SDA Vsense: R85.2, TP4.1, U2.2 (SDA1)
IsoSPI RX AND: U1.4, U27.38 (GPIO30)
IsoSPI RX Debug: U27.39 (GPIO31)
IsoSPI RX H: TP17.1, U1.2, U27.36 (GPIO28), U28.5 (2Y)
IsoSPI RX L: TP17.2, U1.1, U27.37 (GPIO29), U28.3 (1Y)
IsoSPI TX Data: TP1.2, U27.28 (GPIO27), U32.4 (DI)
IsoSPI TX En: TP1.1, U27.27 (GPIO26), U32.3 (DE)
IsoSPI+: J6.1, J11.1, TR10.4 (TX+)
IsoSPI-: J6.2, J11.2, TR10.6 (TX-)
Link Negative: J7.22
Link Positive: J7.13
MUC1-MCU2 TX-RX: R63.1, TP9.2, U11.79 (GPIO2)
MUC2-MCU1 TX-RX: R64.1, TP9.1, U11.78 (GPIO1)
Neg: U23.1
unnamed: BT1.1 (+), BT5.2 (-)
unnamed: BT1.2 (-), R32.2
unnamed: BT3.1 (+), F8.1
unnamed: BT3.2 (-), BT4.1 (+)
unnamed: BT4.2 (-), BT9.2 (-), K12.14, K15.14
unnamed: BT5.1 (+), BT6.1 (+), K9.14, K14.14, R176.1
unnamed: BT6.2 (-), BT7.1 (+)
unnamed: BT7.2 (-), R178.1
unnamed: BT8.1 (+), F1.1
unnamed: BT8.2 (-), BT9.1 (+)
unnamed: C3.2, R8.2, R10.1
unnamed: C4.1, R1.1, R2.2
unnamed: C10.1, C41.2, C42.1, C43.2, C95.2, R40.2, R41.1, R45.2, R47.1, R228.2, R229.1
unnamed: C26.1, J3.14, J3.23, U9.2
unnamed: C26.2, R36.1, U9.1
unnamed: C27.1, R50.1, R80.2
unnamed: C36.1, R46.2, Y1.3
unnamed: C40.1, J3.20, J3.21, U8.2
unnamed: C40.2, R23.1, U8.1
unnamed: C69.1, R58.1, R171.2
unnamed: C118.1, R168.2, Y2.3
unnamed: D2.2 (A), R83.2
unnamed: D3.2 (A), R11.2
unnamed: D4.2 (A), R27.2
unnamed: D5.2 (A), R74.2
unnamed: D8.2 (A), R3.2
unnamed: D12.1 (A1), D13.2 (A2)
unnamed: D13.1 (A1), D22.2 (A2)
unnamed: D18.1 (A1), D50.2 (A2)
unnamed: D19.2 (A), R70.2
unnamed: D20.1 (A1), D27.2 (A2)
unnamed: D21.1 (K), J15.A4 (VBUS), J15.A9 (VBUS), J15.B4 (VBUS), J15.B9 (VBUS)
unnamed: D23.2 (A), R190.2
unnamed: D26.2 (A), R75.2
unnamed: D27.1 (A1), D49.2 (A2)
unnamed: D28.2 (A), R84.2
unnamed: D29.2 (A), R77.2
unnamed: D30.2 (A), J17.A4 (VBUS), J17.A9 (VBUS), J17.B4 (VBUS), J17.B9 (VBUS)
unnamed: D30.1 (K), FB1.1
unnamed: D31.2 (A), R79.2
unnamed: D32.2 (A), R81.1
unnamed: D33.2 (A), R48.2
unnamed: D34.2 (A), R56.2
unnamed: D37.2 (A), R144.2
unnamed: D38.2 (A), R143.2
unnamed: D40.2 (A), R142.2
unnamed: D50.1 (A1), D51.2 (A2)
unnamed: D53.2 (A), J18.A4 (VBUS), J18.A9 (VBUS), J18.B4 (VBUS), J18.B9 (VBUS)
unnamed: D53.1 (K), FB7.1
unnamed: F1.2, R178.4
unnamed: F8.2, R32.1
unnamed: F9.2, K13.1
unnamed: F11.1, K11.14, K12.13, K13.2, K15.13, K17.14
unnamed: F11.2, K11.13, K17.13, K18.2
unnamed: J3.13, R36.2, R42.2
unnamed: J3.15, U20.4
unnamed: J3.16, U10.3
unnamed: J3.17, U10.4
unnamed: J3.18, U20.3
unnamed: J3.22, R37.1
unnamed: J3.24, R42.1
unnamed: J17.A5 (CC1), R53.2
unnamed: J17.B5 (CC2), R55.2
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

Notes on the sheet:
all JLC basic components
3.3V 1A LDO Supply
GPIO4 - GPIO13 on NC header
FC Negative Contactor
Would be cool if it alternates with main
PTC 440V 56Ω
BMB side xfmr center tap has no connection reference to ground to prevent ESD
unused inputs left floating - internal bias
3A max output - 3.3V draws from this rail
Galvanically Isolated Area
100k input impedance 0.14mA typical ADC usage
Terminate unused port per LTC6813 datasheet (100R recommended)
MCU Identification
In tesla packs the shunt is at the mid point of the pack!
Supervisor MCU
5V powers exteral ESP32 LCD also
FC Positive Contactor
Cells Positive Contactor
close to MCU
Extra GPIO
API TTL RS232 Interface
Redundant connectors
isoSPI Transceiver
Shunt Current Sense
Cells Positive Always Live
10V-16V input
Data must be after En
Positives
all JLC basic components except: inductor, 680uf cap
1A max output
Inverter connected to FC port
5V 3A DC-DC Supply
5V 600mA max external ESP32 interface
BatMan Interface
Inverter CAN Interface
Cells Negative Contactor
I2C ADDR: 0x48
requires connection to always live terminal
Contactor AND gate enable output
Main MCU

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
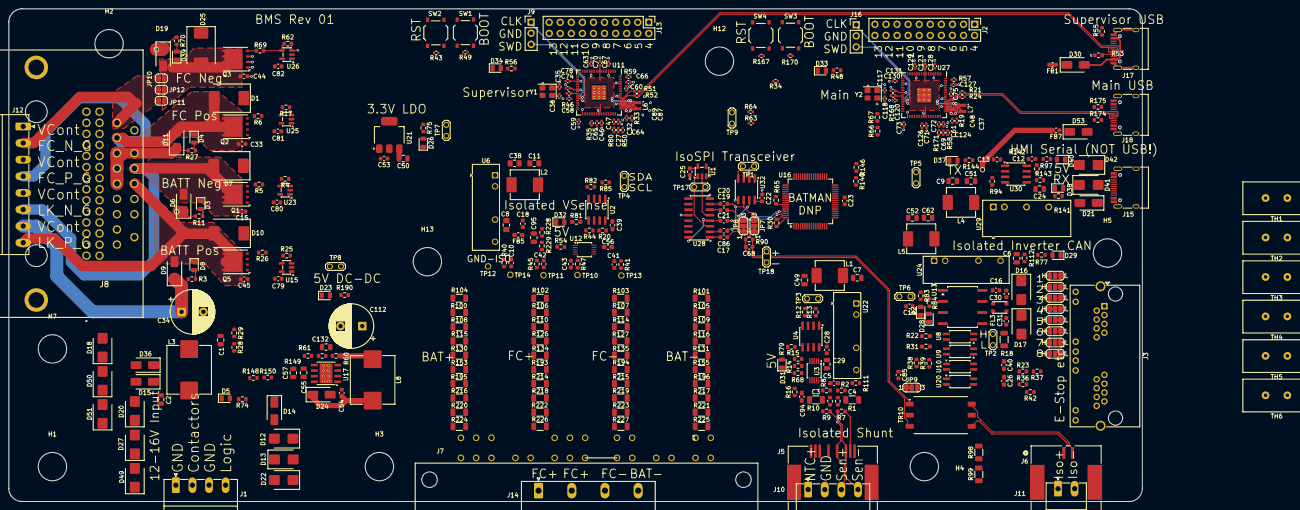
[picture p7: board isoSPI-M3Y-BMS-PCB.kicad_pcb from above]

Board: 4 copper layers, 260.0 x 113.0 mm, 398 parts (0 on the bottom side), 267 nets.

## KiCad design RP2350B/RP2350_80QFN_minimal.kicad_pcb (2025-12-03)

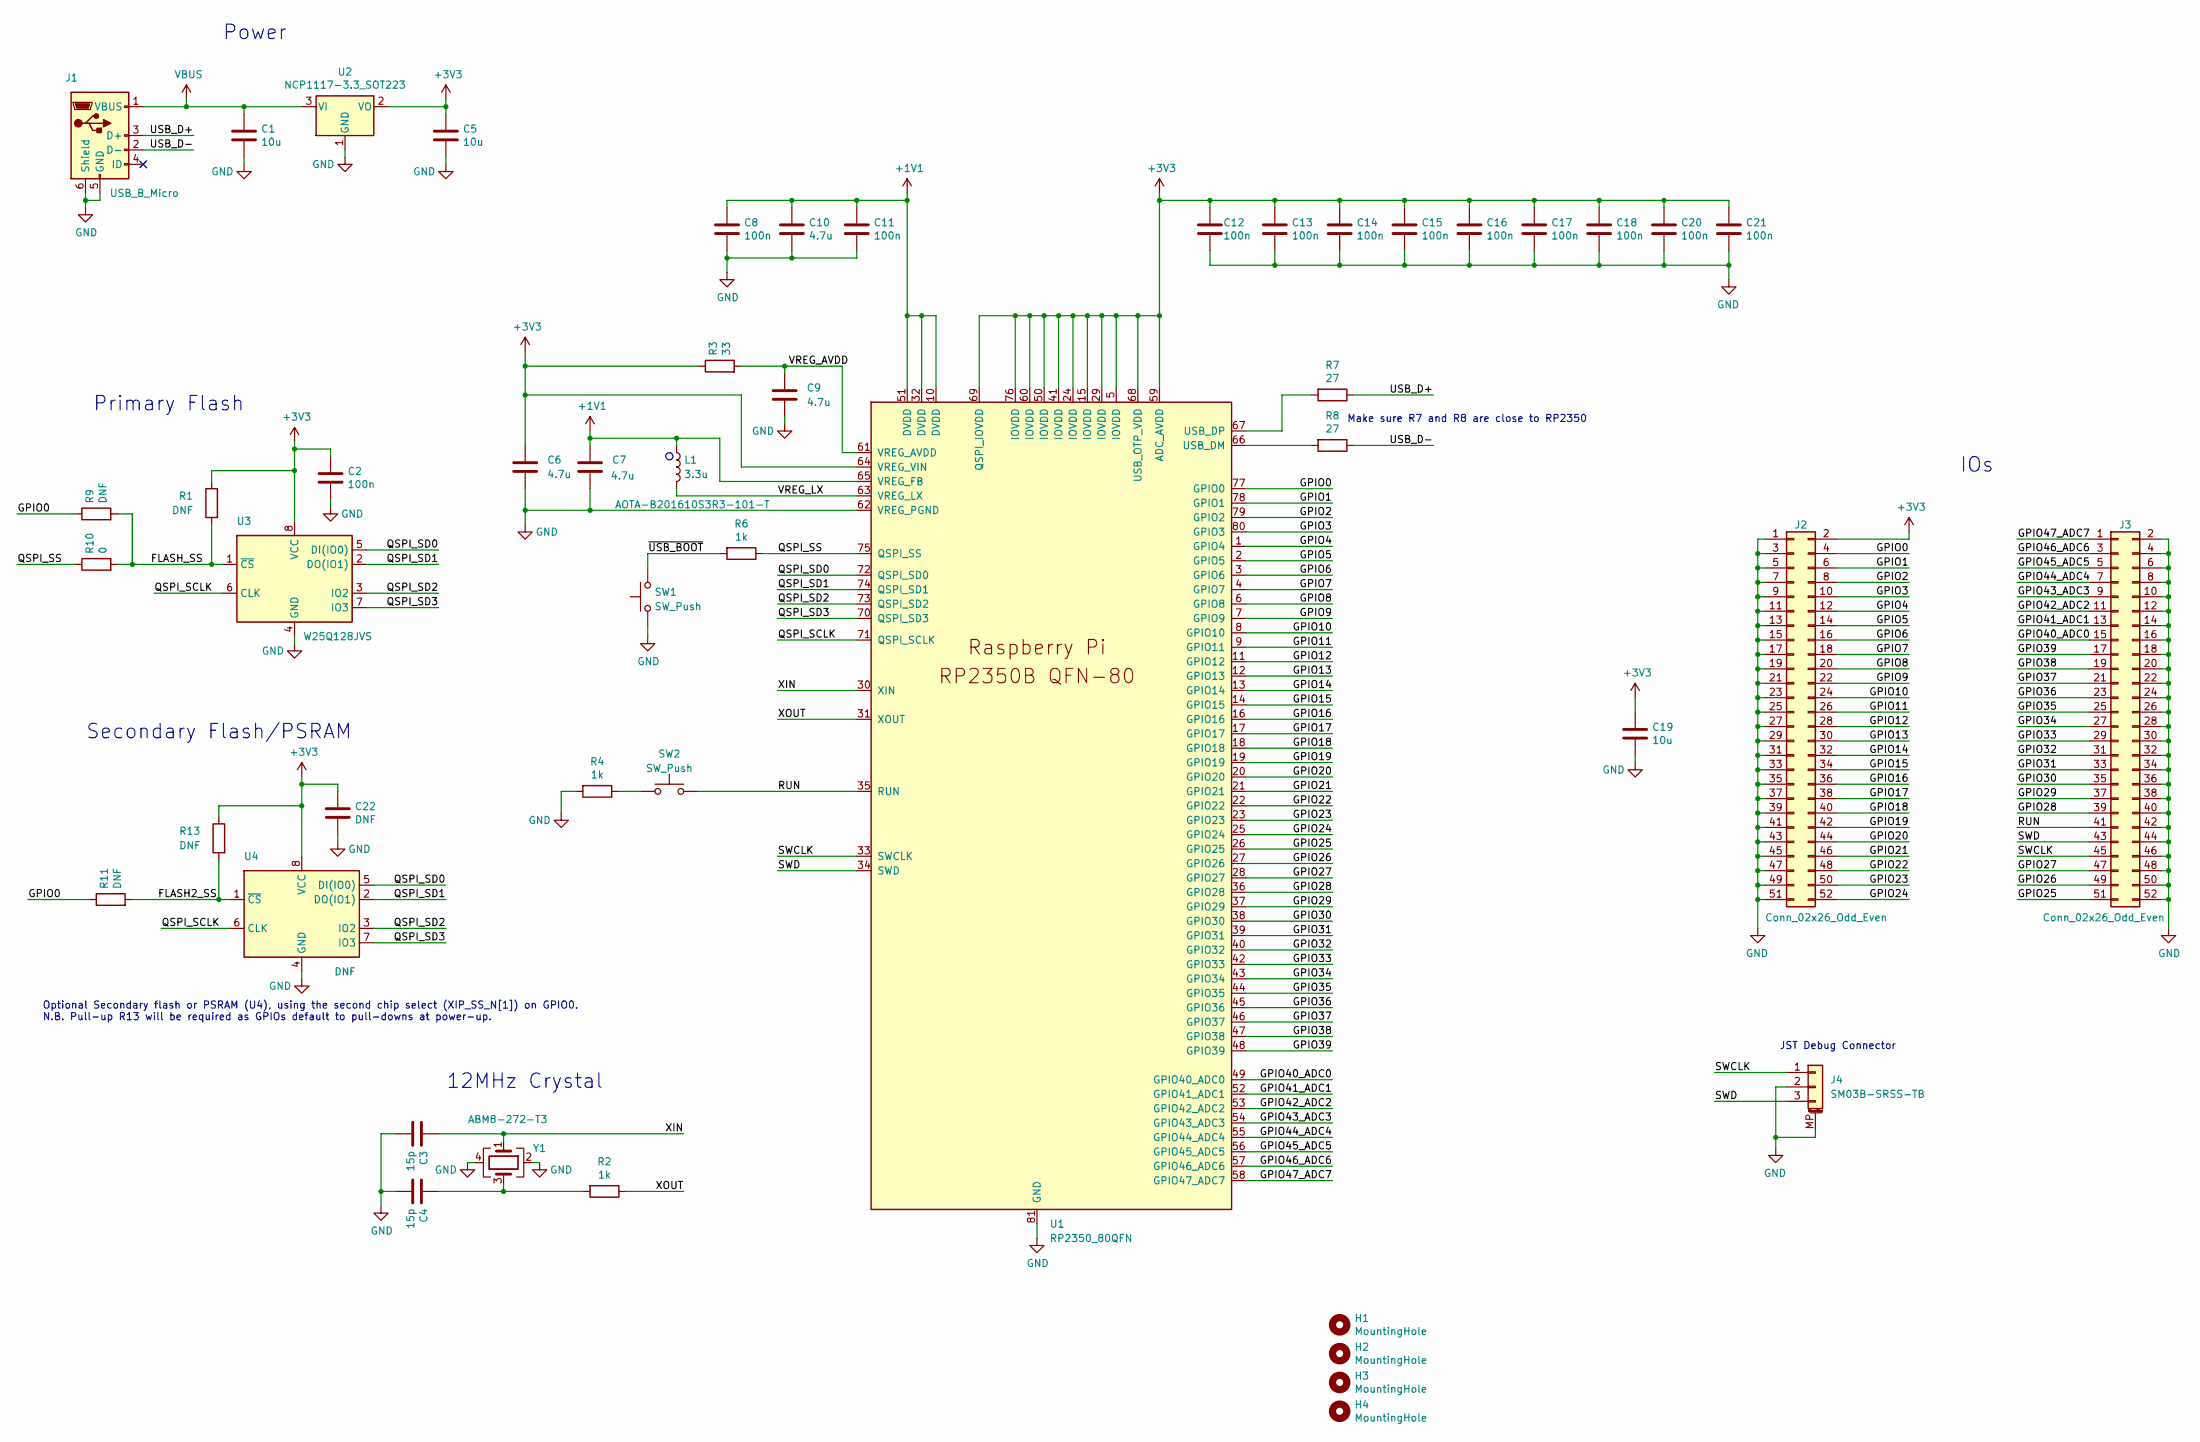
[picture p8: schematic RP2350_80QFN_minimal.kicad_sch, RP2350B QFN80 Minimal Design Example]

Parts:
C1, C5, C19: 10u; C_0805_2012Metric
C2, C8, C11, C12, C13, C14, C15, C16, C17, C18, C20, C21: 100n; C_0402_1005Metric
C3, C4: 15p; C_0402_1005Metric
C6, C7: 4.7u; C_0402_1005Metric_small_pads
C9, C10: 4.7u; C_0402_1005Metric
C22: DNF; C_0402_1005Metric
H1, H2, H3, H4: MountingHole; MountingHole_2.7mm_M2.5
J1: USB_B_Micro; USB_Micro-B_Amphenol_10103594-0001LF_Horizontal
J2, J3: Conn_02x26_Odd_Even; PinHeader_2x26_P2.54mm_Vertical
J4: SM03B-SRSS-TB; JST_SH_SM03B-SRSS-TB_1x03-1MP_P1.00mm_Horizontal
L1: 3.3u; L_pol_2016
R1, R9, R11, R13: DNF; R_0402_1005Metric
R2, R4, R6: 1k; R_0402_1005Metric
R3: 33; R_0402_1005Metric
R7, R8: 27; R_0402_1005Metric
R10: 0; R_0402_1005Metric
SW1, SW2: SW_Push; SW_Push_1P1T_NO_Vertical_Wuerth_434133025816
U1: RP2350_80QFN; RP2350-QFN-80-1EP_10x10_P0.4mm_EP3.4x3.4mm_ThermalVias
U2: NCP1117-3.3_SOT223; SOT-223-3_TabPin2
U3: W25Q128JVS; SOIC-8_5.23x5.23mm_P1.27mm
U4: DNF; SOIC-8_5.23x5.23mm_P1.27mm
Y1: ABM8-272-T3; Crystal_SMD_3225-4Pin_3.2x2.5mm

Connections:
+1V1: C7.1, C8.1, C10.1, C11.1, L1.1, U1.10 (DVDD), U1.32 (DVDD), U1.51 (DVDD), U1.65 (VREG_FB)
+3V3: C2.1, C5.1, C6.1, C12.1, C13.1, C14.1, C15.1, C16.1, C17.1, C18.1, C19.1, C20.1, C21.1, C22.1, J2.2, R1.1, R3.1, R13.1, U1.5 (IOVDD), U1.15 (IOVDD), U1.24 (IOVDD), U1.29 (IOVDD), U1.41 (IOVDD), U1.50 (IOVDD), U1.59 (ADC_AVDD), U1.60 (IOVDD), U1.64 (VREG_VIN), U1.68 (USB_OTP_VDD), U1.69 (QSPI_IOVDD), U1.76 (IOVDD), U2.2 (VO), U3.8 (VCC), U4.8 (VCC)
/FLASH2_SS: R11.2, R13.2, U4.1 (~CS)
/FLASH_SS: R1.2, R9.2, R10.2, U3.1 (~CS)
/GPIO0: J2.4, R9.1, R11.1, U1.77 (GPIO0)
/GPIO1: J2.6, U1.78 (GPIO1)
/GPIO2: J2.8, U1.79 (GPIO2)
/GPIO3: J2.10, U1.80 (GPIO3)
/GPIO4: J2.12, U1.1 (GPIO4)
/GPIO5: J2.14, U1.2 (GPIO5)
/GPIO6: J2.16, U1.3 (GPIO6)
/GPIO7: J2.18, U1.4 (GPIO7)
/GPIO8: J2.20, U1.6 (GPIO8)
/GPIO9: J2.22, U1.7 (GPIO9)
/GPIO10: J2.24, U1.8 (GPIO10)
/GPIO11: J2.26, U1.9 (GPIO11)
/GPIO12: J2.28, U1.11 (GPIO12)
/GPIO13: J2.30, U1.12 (GPIO13)
/GPIO14: J2.32, U1.13 (GPIO14)
/GPIO15: J2.34, U1.14 (GPIO15)
/GPIO16: J2.36, U1.16 (GPIO16)
/GPIO17: J2.38, U1.17 (GPIO17)
/GPIO18: J2.40, U1.18 (GPIO18)
/GPIO19: J2.42, U1.19 (GPIO19)
/GPIO20: J2.44, U1.20 (GPIO20)
/GPIO21: J2.46, U1.21 (GPIO21)
/GPIO22: J2.48, U1.22 (GPIO22)
/GPIO23: J2.50, U1.23 (GPIO23)
/GPIO24: J2.52, U1.25 (GPIO24)
/GPIO25: J3.51, U1.26 (GPIO25)
/GPIO26: J3.49, U1.27 (GPIO26)
/GPIO27: J3.47, U1.28 (GPIO27)
/GPIO28: J3.39, U1.36 (GPIO28)
/GPIO29: J3.37, U1.37 (GPIO29)
/GPIO30: J3.35, U1.38 (GPIO30)
/GPIO31: J3.33, U1.39 (GPIO31)
/GPIO32: J3.31, U1.40 (GPIO32)
/GPIO33: J3.29, U1.42 (GPIO33)
/GPIO34: J3.27, U1.43 (GPIO34)
/GPIO35: J3.25, U1.44 (GPIO35)
/GPIO36: J3.23, U1.45 (GPIO36)
/GPIO37: J3.21, U1.46 (GPIO37)
/GPIO38: J3.19, U1.47 (GPIO38)
/GPIO39: J3.17, U1.48 (GPIO39)
/GPIO40_ADC0: J3.15, U1.49 (GPIO40_ADC0)
/GPIO41_ADC1: J3.13, U1.52 (GPIO41_ADC1)
/GPIO42_ADC2: J3.11, U1.53 (GPIO42_ADC2)
/GPIO43_ADC3: J3.9, U1.54 (GPIO43_ADC3)
/GPIO44_ADC4: J3.7, U1.55 (GPIO44_ADC4)
/GPIO45_ADC5: J3.5, U1.56 (GPIO45_ADC5)
/GPIO46_ADC6: J3.3, U1.57 (GPIO46_ADC6)
/GPIO47_ADC7: J3.1, U1.58 (GPIO47_ADC7)
/QSPI_SCLK: U1.71 (QSPI_SCLK), U3.6 (CLK), U4.6 (CLK)
/QSPI_SD0: U1.72 (QSPI_SD0), U3.5 (DI(IO0)), U4.5 (DI(IO0))
/QSPI_SD1: U1.74 (QSPI_SD1), U3.2 (DO(IO1)), U4.2 (DO(IO1))
/QSPI_SD2: U1.73 (QSPI_SD2), U3.3 (IO2), U4.3 (IO2)
/QSPI_SD3: U1.70 (QSPI_SD3), U3.7 (IO3), U4.7 (IO3)
/QSPI_SS: R6.1, R10.1, U1.75 (QSPI_SS)
/RUN: J3.41, SW2.2, U1.35 (RUN)
/SWCLK: J3.45, J4.1, U1.33 (SWCLK)
/SWD: J3.43, J4.3, U1.34 (SWD)
/USB_D+: J1.3 (D+), R7.1
/USB_D-: J1.2 (D-), R8.1
/VREG_AVDD: C9.1, R3.2, U1.61 (VREG_AVDD)
/VREG_LX: L1.2, U1.63 (VREG_LX)
/XIN: C3.1, U1.30 (XIN), Y1.1
/XOUT: R2.1, U1.31 (XOUT)
/~USB_BOOT: R6.2, SW1.2
GND: C1.2, C2.2, C3.2, C4.2, C5.2, C6.2, C7.2, C8.2, C9.2, C10.2, C11.2, C12.2, C13.2, C14.2, C15.2, C16.2, C17.2, C18.2, C19.2, C20.2, C21.2, C22.2, J1.5 (GND), J1.6 (Shield), J2.1, J2.3, J2.5, J2.7, J2.9, J2.11, J2.13, J2.15, J2.17, J2.19, J2.21, J2.23, J2.25, J2.27, J2.29, J2.31, J2.33, J2.35, J2.37, J2.39, J2.41, J2.43, J2.45, J2.47, J2.49, J2.51, J3.2, J3.4, J3.6, J3.8, J3.10, J3.12, J3.14, J3.16, J3.18, J3.20, J3.22, J3.24, J3.26, J3.28, J3.30, J3.32, J3.34, J3.36, J3.38, J3.40, J3.42, J3.44, J3.46, J3.48, J3.50, J3.52, J4.2, J4.MP (MountPin), R4.2, SW1.1, U1.62 (VREG_PGND), U1.81 (GND), U2.1 (GND), U3.4 (GND), U4.4 (GND), Y1.2, Y1.4
unnamed: C4.1, R2.2, Y1.3
unnamed: R4.1, SW2.1
unnamed: R8.2, U1.66 (USB_DM)
unnamed: R7.2, U1.67 (USB_DP)
VBUS: C1.1, J1.1 (VBUS), U2.3 (VI)

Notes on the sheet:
Optional Secondary flash or PSRAM (U4), using the second chip select (XIP_SS_N[1]) on GPIO0. N.B. Pull-up R13 will be required as GPIOs default to pull-downs at power-up.
IOs
12MHz Crystal
Primary Flash
JST Debug Connector
Make sure R7 and R8 are close to RP2350
Secondary Flash/PSRAM
Power

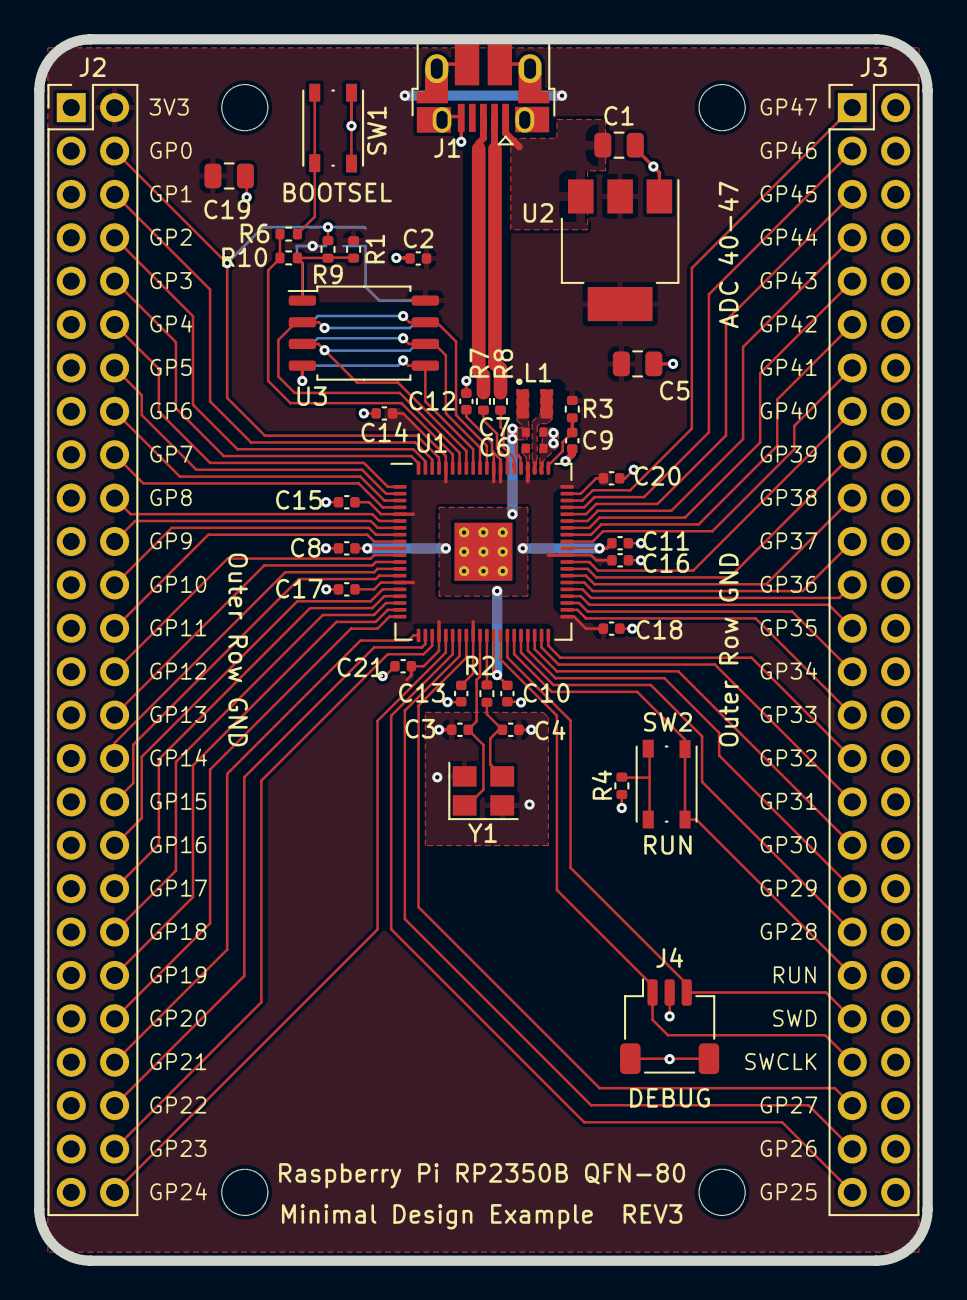
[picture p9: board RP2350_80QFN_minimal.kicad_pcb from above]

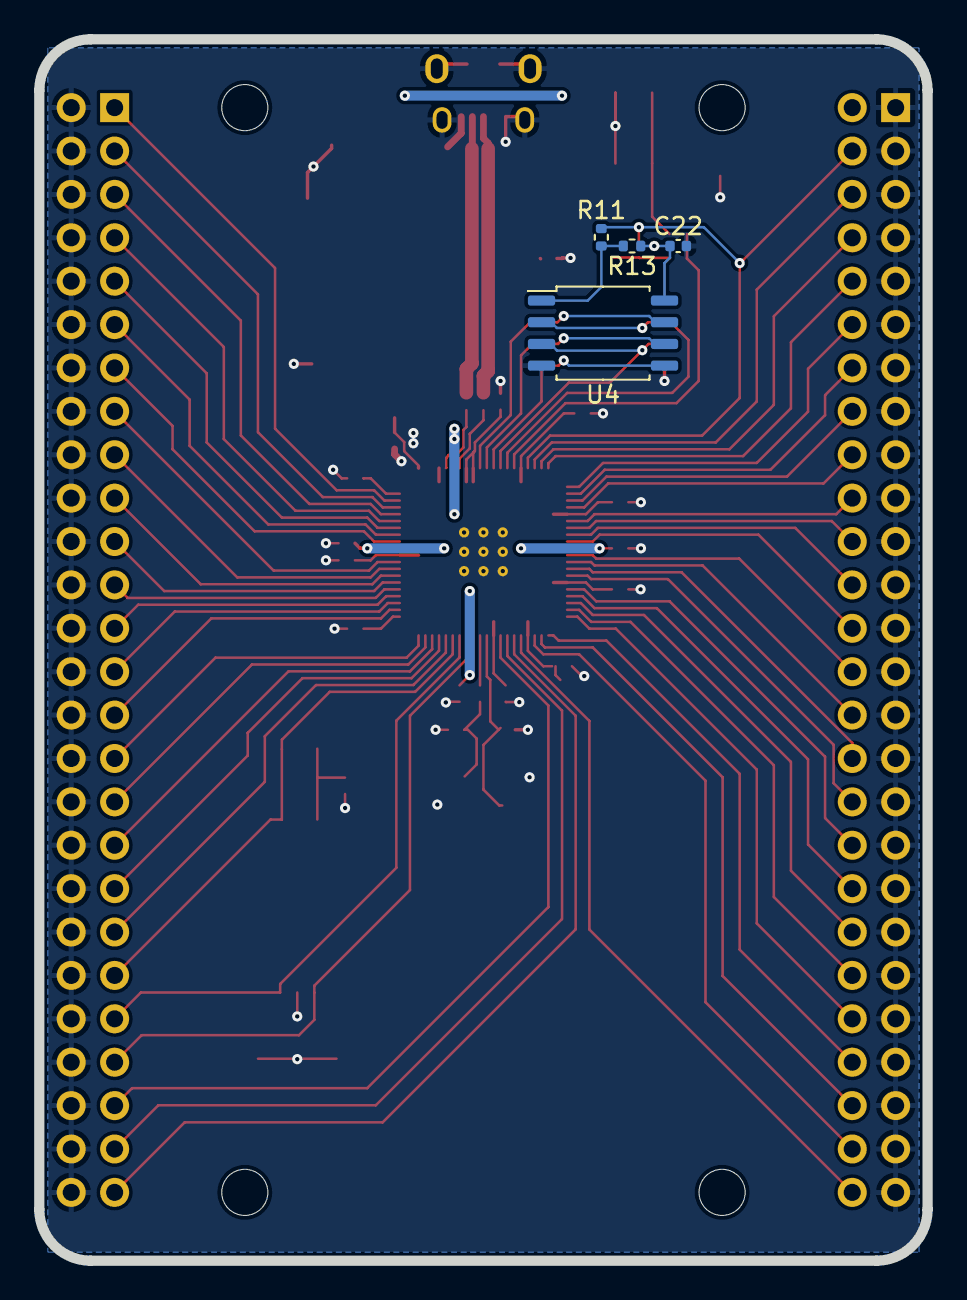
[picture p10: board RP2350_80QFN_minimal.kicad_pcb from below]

Board: 2 copper layers, 52.0 x 71.5 mm, 49 parts (4 on the bottom side), 74 nets.

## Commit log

2025-12-03 update readme and add text to pcb
    [isoSPI-M3Y-BMS-PCB.kicad_pcb]
2025-12-03 connecting main mcu pins
    [isoSPI-M3Y-BMS-PCB.kicad_pcb, isoSPI-M3Y-BMS-PCB.kicad_sch]
2025-12-03 fix typo
    [isoSPI-M3Y-BMS-PCB.kicad_sch]
2025-12-05 routed dc-dc
    [isoSPI-M3Y-BMS-PCB.kicad_sch]
2025-12-05 route ptc
    [isoSPI-M3Y-BMS-PCB.kicad_sch]
2025-12-05 update hole size for PTC
2025-12-05 added more ground pins
    [isoSPI-M3Y-BMS-PCB.kicad_sch]
2025-12-05 lots of updates
    [isoSPI-M3Y-BMS-PCB.kicad_sch]
2025-12-07 more tweaks
    [isoSPI-M3Y-BMS-PCB.kicad_sch]
2025-12-09 REV 0 Ordered!!!
    [bom.csv, designators.csv, isoSPI-M3Y-BMS-PCB.kicad_sch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]
2026-01-01 working on next revision now
    [isoSPI-M3Y-BMS-PCB.kicad_sch]
2026-01-22 WIP - diverting after this to new mounting holes
    [isoSPI-M3Y-BMS-PCB.kicad_sch]

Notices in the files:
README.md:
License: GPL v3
